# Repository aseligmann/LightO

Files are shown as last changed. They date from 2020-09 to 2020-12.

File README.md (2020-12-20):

# LightO

LightO is an open remote-controlled light project.

The project is based around an ESP32 driving a string of addressable LEDs, in this case a custom PCB with 61 SK6812 RGBW LEDs.

The user is able to control the LightO through an intuitive web-based interface, consisting of color-wheel and slider control.
The brightness of the light is user-controlled and can be driven at up to roughly 15 W, for an eye-scorching brightness level.

The LightO has 3 modes which can be selected from the interface:

* **Colour** - User defines a colour to display
* **Candle** - Simulates a flickering candle
* **Cycle** - Cycles through the colour-spectrum

The light is powered by a single USB-C port. 

### Images
Front

Front

Left side

Back

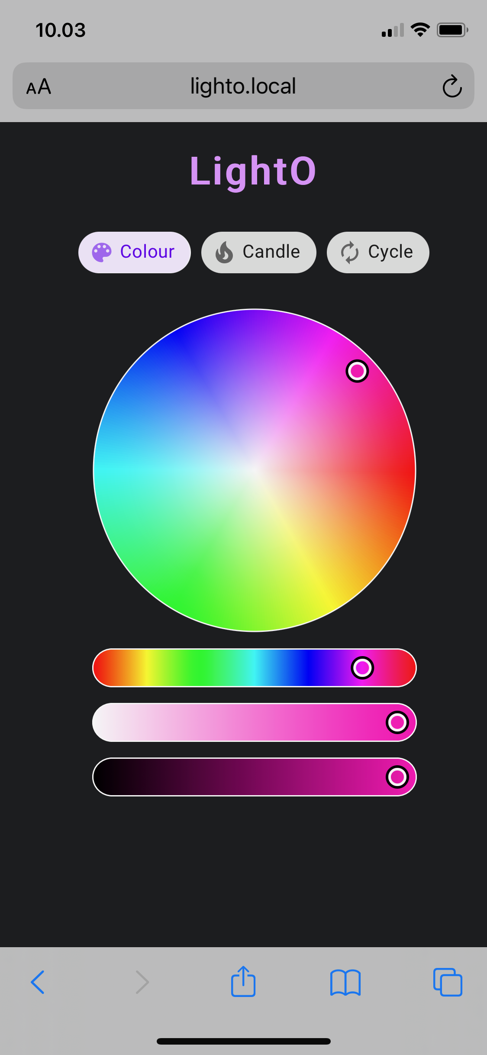
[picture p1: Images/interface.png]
Interface


### Features
- Full control of colour and brightness (RGBW channels) for all LEDs
- USB-C powered
- WiFi based control with user-centered design
- Intuitive captive AP for setup

### Development
- [ ] Provide schematic for ESP32 piggyback board
- [ ] Wake-up mode simulating a sunrise at a userdefined time
- [ ] Migrate code to PlatformIO
- [ ] Integrate USB-C PD and ESP32 on LED PCB

### Bill of Materials

#### PCB
* 1x 160 mm LightO PCB (light_160mm_v1_0_2020-04-21)
* 61x SK6812 LEDs
* 61x 5050 LED lenses, wide angle (optional)
* 61x 0805 100 nF capacitors
* 2x JST-XH 2-pin straight connectors

#### ESP32
* 1x ESP32 development board
* 1x 100 uF capacitor
* 2x 330 Ohm resistors

#### Power-delivery
* 1x USB-C PD module (ZY12PDN)

#### Misc.
* 7x M3 bolts (16 mm)
* 7x M3 nuts
* 3x 2.2x9.5 self-tapping screws

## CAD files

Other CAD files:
Hardware/Model/Parts/AcrylicFront/AcrylicFront_v1.0.DWG

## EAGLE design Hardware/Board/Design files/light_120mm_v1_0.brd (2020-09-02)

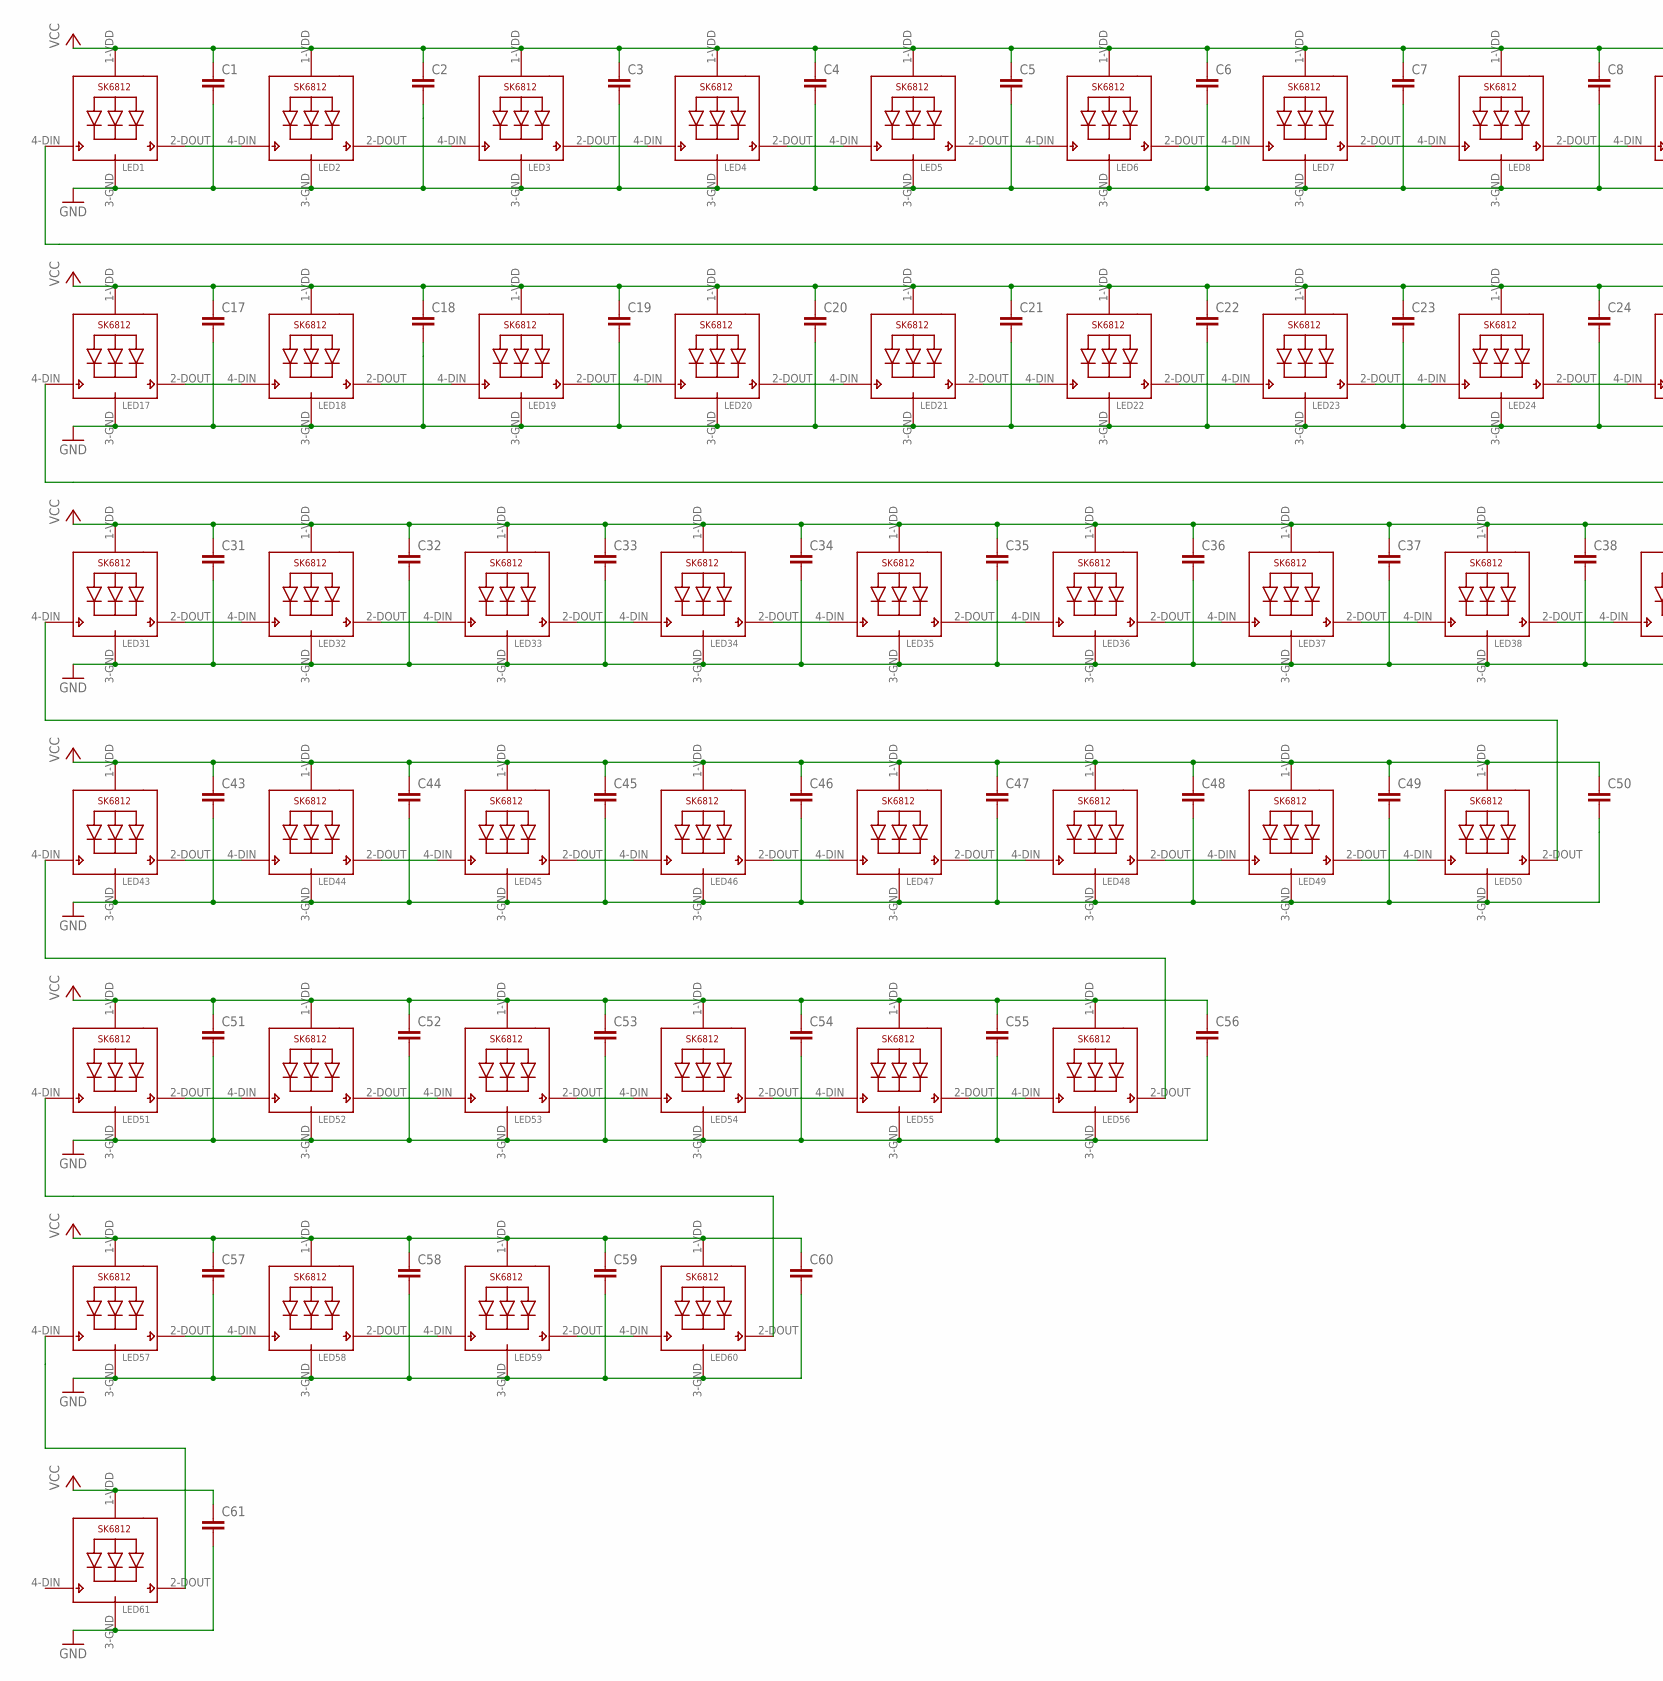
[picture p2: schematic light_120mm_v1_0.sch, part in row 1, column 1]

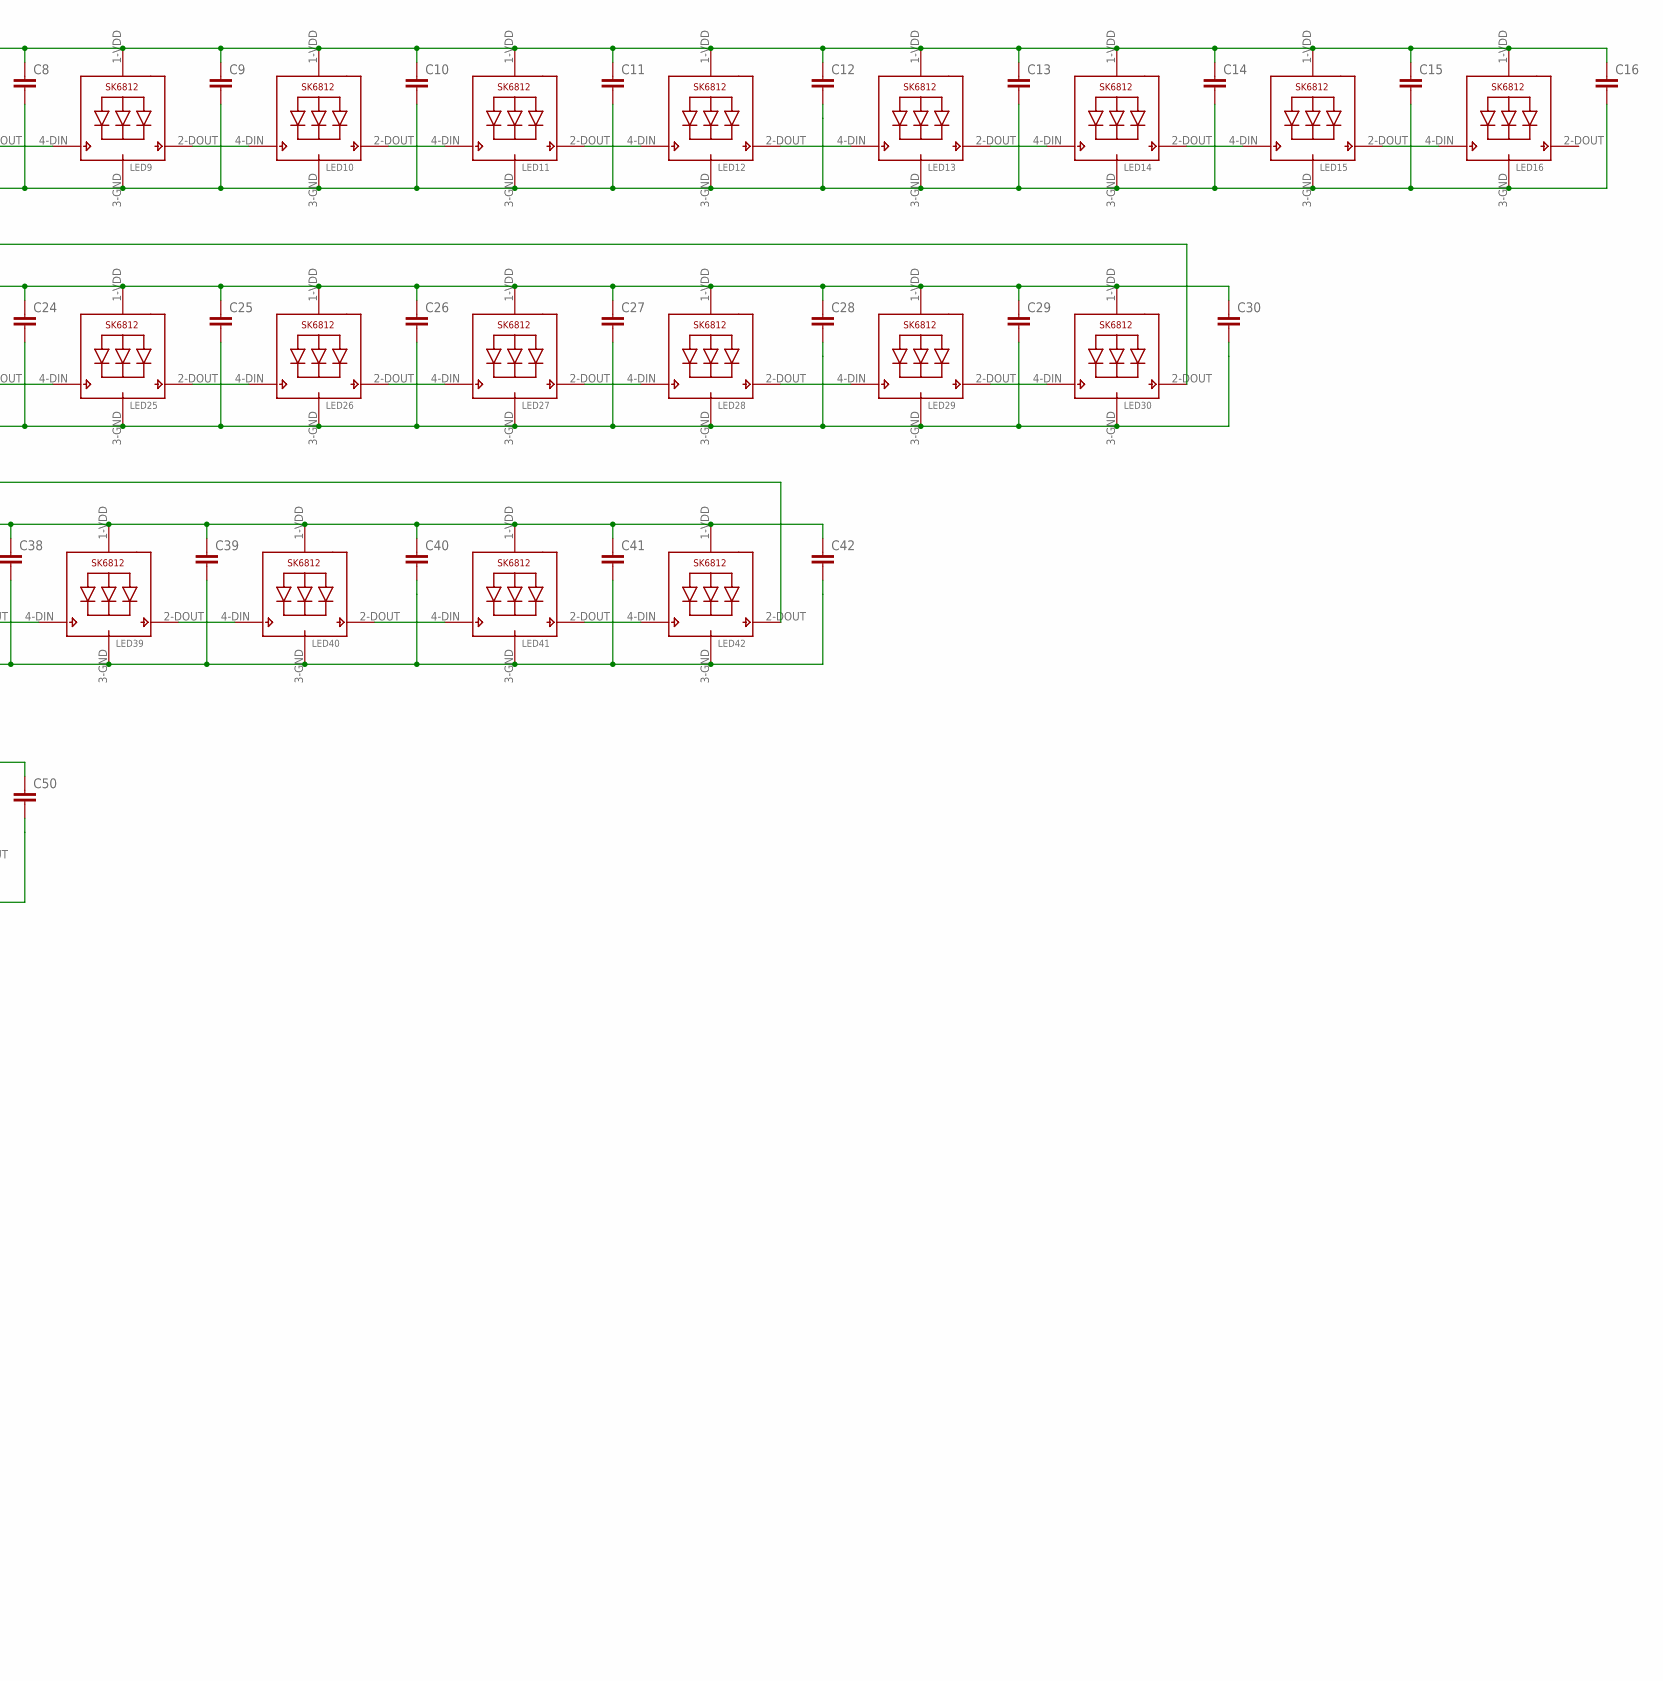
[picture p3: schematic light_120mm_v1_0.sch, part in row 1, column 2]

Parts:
C1, C2, C3, C4, C5, C6, C7, C8, C9, C10, C11, C12, C13, C14, C15, C16, C17, C18, C19, C20, C21, C22, C23, C24, C25, C26, C27, C28, C29, C30, C31, C32, C33, C34, C35, C36, C37, C38, C39, C40, C41, C42, C43, C44, C45, C46, C47, C48, C49, C50, C51, C52, C53, C54, C55, C56, C57, C58, C59, C60, C61: C-EUC0805; C0805
LED1, LED2, LED3, LED4, LED5, LED6, LED7, LED8, LED9, LED10, LED11, LED12, LED13, LED14, LED15, LED16, LED17, LED18, LED19, LED20, LED21, LED22, LED23, LED24, LED25, LED26, LED27, LED28, LED29, LED30, LED31, LED32, LED33, LED34, LED35, LED36, LED37, LED38, LED39, LED40, LED41, LED42, LED43, LED44, LED45, LED46, LED47, LED48, LED49, LED50, LED51, LED52, LED53, LED54, LED55, LED56, LED57, LED58, LED59, LED60, LED61: SK6812_5050W; LED5050_W

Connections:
GND: C1.2, C2.2, C3.2, C4.2, C5.2, C6.2, C7.2, C8.2, C9.2, C10.2, C11.2, C12.2, C13.2, C14.2, C15.2, C16.2, C17.2, C18.2, C19.2, C20.2, C21.2, C22.2, C23.2, C24.2, C25.2, C26.2, C27.2, C28.2, C29.2, C30.2, C31.2, C32.2, C33.2, C34.2, C35.2, C36.2, C37.2, C38.2, C39.2, C40.2, C41.2, C42.2, C43.2, C44.2, C45.2, C46.2, C47.2, C48.2, C49.2, C50.2, C51.2, C52.2, C53.2, C54.2, C55.2, C56.2, C57.2, C58.2, C59.2, C60.2, C61.2, LED1.3-GND (GND), LED2.3-GND (GND), LED3.3-GND (GND), LED4.3-GND (GND), LED5.3-GND (GND), LED6.3-GND (GND), LED7.3-GND (GND), LED8.3-GND (GND), LED9.3-GND (GND), LED10.3-GND (GND), LED11.3-GND (GND), LED12.3-GND (GND), LED13.3-GND (GND), LED14.3-GND (GND), LED15.3-GND (GND), LED16.3-GND (GND), LED17.3-GND (GND), LED18.3-GND (GND), LED19.3-GND (GND), LED20.3-GND (GND), LED21.3-GND (GND), LED22.3-GND (GND), LED23.3-GND (GND), LED24.3-GND (GND), LED25.3-GND (GND), LED26.3-GND (GND), LED27.3-GND (GND), LED28.3-GND (GND), LED29.3-GND (GND), LED30.3-GND (GND), LED31.3-GND (GND), LED32.3-GND (GND), LED33.3-GND (GND), LED34.3-GND (GND), LED35.3-GND (GND), LED36.3-GND (GND), LED37.3-GND (GND), LED38.3-GND (GND), LED39.3-GND (GND), LED40.3-GND (GND), LED41.3-GND (GND), LED42.3-GND (GND), LED43.3-GND (GND), LED44.3-GND (GND), LED45.3-GND (GND), LED46.3-GND (GND), LED47.3-GND (GND), LED48.3-GND (GND), LED49.3-GND (GND), LED50.3-GND (GND), LED51.3-GND (GND), LED52.3-GND (GND), LED53.3-GND (GND), LED54.3-GND (GND), LED55.3-GND (GND), LED56.3-GND (GND), LED57.3-GND (GND), LED58.3-GND (GND), LED59.3-GND (GND), LED60.3-GND (GND), LED61.3-GND (GND)
unnamed: LED1.2-DOUT (DO), LED2.4-DIN (DI)
unnamed: LED2.2-DOUT (DO), LED3.4-DIN (DI)
unnamed: LED3.2-DOUT (DO), LED4.4-DIN (DI)
unnamed: LED4.2-DOUT (DO), LED5.4-DIN (DI)
unnamed: LED5.2-DOUT (DO), LED6.4-DIN (DI)
unnamed: LED6.2-DOUT (DO), LED7.4-DIN (DI)
unnamed: LED7.2-DOUT (DO), LED8.4-DIN (DI)
unnamed: LED8.2-DOUT (DO), LED9.4-DIN (DI)
unnamed: LED9.2-DOUT (DO), LED10.4-DIN (DI)
unnamed: LED10.2-DOUT (DO), LED11.4-DIN (DI)
unnamed: LED11.2-DOUT (DO), LED12.4-DIN (DI)
unnamed: LED12.2-DOUT (DO), LED13.4-DIN (DI)
unnamed: LED13.2-DOUT (DO), LED14.4-DIN (DI)
unnamed: LED14.2-DOUT (DO), LED15.4-DIN (DI)
unnamed: LED15.2-DOUT (DO), LED16.4-DIN (DI)
unnamed: LED43.4-DIN (DI), LED56.2-DOUT (DO)
unnamed: LED17.2-DOUT (DO), LED18.4-DIN (DI)
unnamed: LED18.2-DOUT (DO), LED19.4-DIN (DI)
unnamed: LED19.2-DOUT (DO), LED20.4-DIN (DI)
unnamed: LED20.2-DOUT (DO), LED21.4-DIN (DI)
unnamed: LED21.2-DOUT (DO), LED22.4-DIN (DI)
unnamed: LED22.2-DOUT (DO), LED23.4-DIN (DI)
unnamed: LED23.2-DOUT (DO), LED24.4-DIN (DI)
unnamed: LED24.2-DOUT (DO), LED25.4-DIN (DI)
unnamed: LED25.2-DOUT (DO), LED26.4-DIN (DI)
unnamed: LED26.2-DOUT (DO), LED27.4-DIN (DI)
unnamed: LED27.2-DOUT (DO), LED28.4-DIN (DI)
unnamed: LED28.2-DOUT (DO), LED29.4-DIN (DI)
unnamed: LED29.2-DOUT (DO), LED30.4-DIN (DI)
unnamed: LED31.4-DIN (DI), LED50.2-DOUT (DO)
unnamed: LED31.2-DOUT (DO), LED32.4-DIN (DI)
unnamed: LED32.2-DOUT (DO), LED33.4-DIN (DI)
unnamed: LED33.2-DOUT (DO), LED34.4-DIN (DI)
unnamed: LED34.2-DOUT (DO), LED35.4-DIN (DI)
unnamed: LED35.2-DOUT (DO), LED36.4-DIN (DI)
unnamed: LED36.2-DOUT (DO), LED37.4-DIN (DI)
unnamed: LED37.2-DOUT (DO), LED38.4-DIN (DI)
unnamed: LED38.2-DOUT (DO), LED39.4-DIN (DI)
unnamed: LED39.2-DOUT (DO), LED40.4-DIN (DI)
unnamed: LED40.2-DOUT (DO), LED41.4-DIN (DI)
unnamed: LED41.2-DOUT (DO), LED42.4-DIN (DI)
unnamed: LED17.4-DIN (DI), LED42.2-DOUT (DO)
unnamed: LED43.2-DOUT (DO), LED44.4-DIN (DI)
unnamed: LED44.2-DOUT (DO), LED45.4-DIN (DI)
unnamed: LED45.2-DOUT (DO), LED46.4-DIN (DI)
unnamed: LED46.2-DOUT (DO), LED47.4-DIN (DI)
unnamed: LED47.2-DOUT (DO), LED48.4-DIN (DI)
unnamed: LED48.2-DOUT (DO), LED49.4-DIN (DI)
unnamed: LED49.2-DOUT (DO), LED50.4-DIN (DI)
unnamed: LED1.4-DIN (DI), LED30.2-DOUT (DO)
unnamed: LED51.2-DOUT (DO), LED52.4-DIN (DI)
unnamed: LED52.2-DOUT (DO), LED53.4-DIN (DI)
unnamed: LED53.2-DOUT (DO), LED54.4-DIN (DI)
unnamed: LED54.2-DOUT (DO), LED55.4-DIN (DI)
unnamed: LED55.2-DOUT (DO), LED56.4-DIN (DI)
unnamed: LED57.4-DIN (DI), LED61.2-DOUT (DO)
unnamed: LED57.2-DOUT (DO), LED58.4-DIN (DI)
unnamed: LED58.2-DOUT (DO), LED59.4-DIN (DI)
unnamed: LED59.2-DOUT (DO), LED60.4-DIN (DI)
unnamed: LED51.4-DIN (DI), LED60.2-DOUT (DO)
VCC: C1.1, C2.1, C3.1, C4.1, C5.1, C6.1, C7.1, C8.1, C9.1, C10.1, C11.1, C12.1, C13.1, C14.1, C15.1, C16.1, C17.1, C18.1, C19.1, C20.1, C21.1, C22.1, C23.1, C24.1, C25.1, C26.1, C27.1, C28.1, C29.1, C30.1, C31.1, C32.1, C33.1, C34.1, C35.1, C36.1, C37.1, C38.1, C39.1, C40.1, C41.1, C42.1, C43.1, C44.1, C45.1, C46.1, C47.1, C48.1, C49.1, C50.1, C51.1, C52.1, C53.1, C54.1, C55.1, C56.1, C57.1, C58.1, C59.1, C60.1, C61.1, LED1.1-VDD (VDD), LED2.1-VDD (VDD), LED3.1-VDD (VDD), LED4.1-VDD (VDD), LED5.1-VDD (VDD), LED6.1-VDD (VDD), LED7.1-VDD (VDD), LED8.1-VDD (VDD), LED9.1-VDD (VDD), LED10.1-VDD (VDD), LED11.1-VDD (VDD), LED12.1-VDD (VDD), LED13.1-VDD (VDD), LED14.1-VDD (VDD), LED15.1-VDD (VDD), LED16.1-VDD (VDD), LED17.1-VDD (VDD), LED18.1-VDD (VDD), LED19.1-VDD (VDD), LED20.1-VDD (VDD), LED21.1-VDD (VDD), LED22.1-VDD (VDD), LED23.1-VDD (VDD), LED24.1-VDD (VDD), LED25.1-VDD (VDD), LED26.1-VDD (VDD), LED27.1-VDD (VDD), LED28.1-VDD (VDD), LED29.1-VDD (VDD), LED30.1-VDD (VDD), LED31.1-VDD (VDD), LED32.1-VDD (VDD), LED33.1-VDD (VDD), LED34.1-VDD (VDD), LED35.1-VDD (VDD), LED36.1-VDD (VDD), LED37.1-VDD (VDD), LED38.1-VDD (VDD), LED39.1-VDD (VDD), LED40.1-VDD (VDD), LED41.1-VDD (VDD), LED42.1-VDD (VDD), LED43.1-VDD (VDD), LED44.1-VDD (VDD), LED45.1-VDD (VDD), LED46.1-VDD (VDD), LED47.1-VDD (VDD), LED48.1-VDD (VDD), LED49.1-VDD (VDD), LED50.1-VDD (VDD), LED51.1-VDD (VDD), LED52.1-VDD (VDD), LED53.1-VDD (VDD), LED54.1-VDD (VDD), LED55.1-VDD (VDD), LED56.1-VDD (VDD), LED57.1-VDD (VDD), LED58.1-VDD (VDD), LED59.1-VDD (VDD), LED60.1-VDD (VDD), LED61.1-VDD (VDD)

Board: 2 copper layers, 122 parts (0 on the bottom side), 62 nets, no tracks yet.

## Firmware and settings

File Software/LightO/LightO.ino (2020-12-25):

// Import required libraries
#include "WiFi.h"
#include <ESPmDNS.h> // For user-friendly web address
#include <WiFiClient.h>
//// https://github.com/me-no-dev/ESPAsyncWebServer/issues/418#issuecomment-667976368
#include <WiFiManager.h> // Captive AP to configure new network
WiFiManager wifiManager;
#define WEBSERVER_H
#include "ESPAsyncWebServer.h" // Web server
////
#include "SPIFFS.h" // Data storage
#include "math.h"
#include <NeoPixelBus.h> // LED control


// Debugging //////////////////////////////////////////////////////////////////////////
bool debug = false;


// Multi-core definitions //////////////////////////////////////////////////////////////////////////
TaskHandle_t taskCore0;
TaskHandle_t taskCore1;
SemaphoreHandle_t taskSemaphore;



// LED Definitions //////////////////////////////////////////////////////////////////////////
#define NUM_LEDS 61
#define DATA_PIN 32

#define brightnessDefault 255

// four element pixels, RGBW
NeoPixelBus<NeoGrbwFeature, Neo800KbpsMethod> strip(NUM_LEDS, DATA_PIN);

RgbwColor red = RgbwColor(brightnessDefault, 0, 0, 0);
RgbwColor green = RgbwColor(0, brightnessDefault, 0, 0);
RgbwColor blue = RgbwColor(0, 0, brightnessDefault, 0);
RgbwColor white = RgbwColor(0, 0, 0, brightnessDefault);
RgbwColor black = RgbwColor(0, 0, 0, 0);

//HslColor hslRed(red);
//HslColor hslGreen(green);
//HslColor hslBlue(blue);
//HslColor hslWhite(white);
//HslColor hslBlack(black);

// Set status LED GPIO
const int switchPin = 23;

// Stores LED state
String ledState;

// LED colors
int hue = 0;
int sat = 100;
int val = 100;
int r;
int g;
int b;
int w;
bool colorUpdate;

//// Modes
// Colorwheel
// Candle
int timeCandleWaitR = 0;
int timeCandleWaitG = 0;
int timeCandleR = 0;
int timeCandleG = 0;
// Cycle
int timeCycleStep = 50;
float hueFloat = 0;

// Timing
long t;
long t_prev;


// Server Definitions //////////////////////////////////////////////////////////////////////////
// Variable to hold HTTP request
const char* PARAM_INPUT_1 = "h";
const char* PARAM_INPUT_2 = "s";
const char* PARAM_INPUT_3 = "v";
const char* PARAM_MODE = "mode";

int lampMode = 0;
// 0 = setup
// 1 = colorwheel
// 2 = candle
// 3 = cycle
 
// Create AsyncWebServer object on port 80
AsyncWebServer server(80);

// Toggle GPIO
String handleSwitch(const String& var) {
  Serial.println(var);
  if (var == "STATE") {
    if (digitalRead(switchPin)) {
      ledState = "ON";
    } else {
      ledState = "OFF";
    }
    Serial.print(ledState);
    return ledState;
  }
  return String();
}

int lastColorUpdate = 0;
int intervalColorUpdate = 100; // ms


// LED functions ////////////////////////////////////////////////////////////////////////////////
// Convert from HSV to RGB
void HSV_to_RGB(int hueIn, int satIn, int valIn) {
  int i;
  double f, p, q, t, h, s, v;

  h = max(0.0, min(360.0, (double) hueIn));
  s = max(0.0, min(100.0, (double) satIn));
  v = max(0.0, min(100.0, (double) valIn));

  s /= 100.0;
  v /= 100.0;

  if (s == 0) {
    // Achromatic (grey)
    r = 0;
    g = 0;
    b = 0;
    return;
  }

  h /= 60.0; // sector 0 to 5
  i = (int) floor(h);
  f = h - i; // factorial part of h
  p = v * (1 - s);
  q = v * (1 - s * f);
  t = v * (1 - s * (1 - f));

  if (debug) {
    Serial.println("-------------- HSV_to_RGB --------------");
    Serial.print("h = ");
    Serial.print(h);
    Serial.print(", i = ");
    Serial.print(i);
    Serial.print(", f = ");
    Serial.println(f);
    Serial.print("v = ");
    Serial.print(v);
    Serial.print(", p = ");
    Serial.print(p);
    Serial.print(", q = ");
    Serial.print(q);
    Serial.print(", t = ");
    Serial.print(t);
    Serial.println();
  }
  
  switch (i) {
    case 1:
      r = (int) round(255 * q);
      g = (int) round(255 * v);
      b = (int) round(255 * p);
      break;
    case 2:
      r = (int) round(255 * p);
      g = (int) round(255 * v);
      b = (int) round(255 * t);
      break;
    case 3:
      r = (int) round(255 * p);
      g = (int) round(255 * q);
      b = (int) round(255 * v);
      break;
    case 4:
      r = (int) round(255 * t);
      g = (int) round(255 * p);
      b = (int) round(255 * v);
      break;
    case 5:
      r = (int) round(255 * v);
      g = (int) round(255 * p);
      b = (int) round(255 * q);
      break;
    default: // case 0
      r = (int) round(255 * v);
      g = (int) round(255 * t);
      b = (int) round(255 * p);
      break;
  }
  
  if (debug) {
    Serial.println("-------------- HSV_to_RGB --------------");
    Serial.print("R = ");
    Serial.print(r);
    Serial.print(", G = ");
    Serial.print(g);
    Serial.print(", B = ");
    Serial.print(b);
    Serial.println();
  }
}


// Handle input color
void handleColor(int hueIn, int satIn, int valIn) {
  // We interpret hue as color, saturation as luminance and value as brightness.
  // This is a bit unconventional, but makes for a better user experience
  
  if (debug) {
    Serial.println("============== handleColor INPUT ==============");
    Serial.print("Hue = ");
    Serial.print(hueIn);
    Serial.print(", Sat = ");
    Serial.print(satIn);
    Serial.print(", Val = ");
    Serial.print(valIn);
    Serial.println();
  }
  
  HSV_to_RGB(hueIn, satIn, valIn);
  //RGB_to_RGBW(r, g, b);
  
  float lum = satIn / 100.0;
  float bright = valIn / 100.0;
  
  r = (int) (bright * lum * r);
  g = (int) (bright * lum * g);
  b = (int) (bright * lum * b);
  w = (int) 255 * (bright * (1.0 - lum));

  if (debug) {
    Serial.println("-------------- handleColor OUTPUT --------------");
    Serial.print("R = ");
    Serial.print(r);
    Serial.print(", G = ");
    Serial.print(g);
    Serial.print(", B = ");
    Serial.print(b);
    Serial.print(", W = ");
    Serial.print(w);
    Serial.println();
    Serial.println("===============================================");
    Serial.println();
  }
}


// Convenience function for setting hue, sat and val, and setting the colorUpdate flag
void colorSet(int hueIn, int satIn, int valIn){
  hue = hueIn;
  sat = satIn;
  val = valIn;
  colorUpdate = true;
}


// Set color of select pixels
void colorSelect(RgbwColor color, int pxStart, int pxEnd) {
  for (uint16_t i = pxStart; i < pxEnd; i++) {
    strip.SetPixelColor(i, color);
  }
  strip.Show();
}


// Set color of all pixels
void colorAll(RgbwColor color) {
  colorSelect(color, 0, strip.PixelCount());
}


// Fade from one color to another
void fade(RgbwColor colorStart, RgbwColor colorEnd, float progressInc, int waitMillis) {
  Serial.println("fade()");
  float progress = 0.0;
  while (progress <= 1.0) {
    Serial.print("\tProgress: ");
    Serial.println(progress);
    RgbwColor updatedColor = RgbwColor::LinearBlend(colorStart, colorEnd, progress);
    colorAll(updatedColor);
    delay(waitMillis);
    progress = progress + progressInc;
  }
}


// Cycle through brightness-levels and colors
void cycleColor(int brightness, int waitMillis) {
  Serial.println("cycleColor()");
  if (brightness > 255) {
    brightness = 255;
  }
  if (brightness < 0) {
    brightness = 0;
  }

  Serial.println("\tRED");
  colorAll(RgbwColor(brightness, 0, 0, 0)); // Full RED
  delay(waitMillis);

  Serial.println("\tGREEN");
  colorAll(RgbwColor(0, brightness, 0, 0)); // Full GREEN
  delay(waitMillis);

  Serial.println("\tBLUE");
  colorAll(RgbwColor(0, 0, brightness, 0)); // Full BLUE
  delay(waitMillis);

  Serial.println("\tWHITE");
  colorAll(RgbwColor(0, 0, 0, brightness)); // Full WHITE
  delay(waitMillis);
}


// Cycle through brightness-levels and colors
void cycleAll(int brightnessStart, int brightnessEnd, int steps, int waitFade, int waitColor) {
  Serial.println("cycleAll()");
  float progressInc = 1 / ((float) steps);

  Serial.println("\tRED");
  RgbwColor colorStart = RgbwColor(brightnessStart, 0, 0, 0); // RED
  RgbwColor colorEnd = RgbwColor(brightnessEnd, 0, 0, 0);
  fade(colorStart, colorEnd, progressInc, waitFade);
  delay(waitColor);

  Serial.println("\tBLUE");
  colorStart = RgbwColor(0, brightnessStart, 0, 0); // BLUE
  colorEnd = RgbwColor(0, brightnessEnd, 0, 0);
  fade(colorStart, colorEnd, progressInc, waitFade);
  delay(waitColor);

  Serial.println("\tGREEN");
  colorStart = RgbwColor(0, 0, brightnessStart, 0); // GREEN
  colorEnd = RgbwColor(0, 0, brightnessEnd, 0);
  fade(colorStart, colorEnd, progressInc, waitFade);
  delay(waitColor);

  Serial.println("\tWHITE");
  colorStart = RgbwColor(0, 0, 0, brightnessStart); // WHITE
  colorEnd = RgbwColor(0, 0, 0, brightnessEnd);
  fade(colorStart, colorEnd, progressInc, waitFade);
}


// Set pixels one at a time
void colorWipe(RgbwColor color, int wait) {
  Serial.println("colorWipe()");
  for (int i = 0; i < strip.PixelCount(); i++) { // For each pixel in strip...
    Serial.print("\tLED: ");
    Serial.println(i + 1);
    strip.SetPixelColor(i, color);         //  Set pixel's color (in RAM)
    strip.Show();                          //  Update strip to match
    delay(wait);                           //  Pause for a moment
  }
}


// Go through all 4 colors by setting pixels one at a time
void colorWipeAll(int brightness, int wait) {
  Serial.println("colorWipeAll()");

  Serial.print("\tRED");
  colorWipe(RgbwColor(brightness, 0, 0, 0), wait);

  Serial.print("\tBLUE");
  colorWipe(RgbwColor(0, brightness, 0, 0), wait);

  Serial.print("\tGREEN");
  colorWipe(RgbwColor(0, 0, brightness, 0), wait);

  Serial.print("\tWHITE");
  colorWipe(RgbwColor(0, 0, 0, brightness), wait);
}
















void setup() {
  // Serial port for debugging purposes
  Serial.begin(115200);

  Serial.println();
  Serial.println("Initializing...");
  Serial.flush();

  // Set LED output
  pinMode(switchPin, OUTPUT);

  lampMode = 0;



  // LED stuff ////////////////////////////////////////////////////////////////////////////////
  Serial.println("Setting up LEDs...");
  // Reset all the pixels to the off state
  strip.Begin();
  strip.Show();
  RgbwColor colorWiFi = RgbwColor(0, 0, 255, 0);
  RgbwColor colorServer = RgbwColor(0, 255, 255, 0);
  RgbwColor colorDone = RgbwColor(0, 255, 0, 0);
  RgbwColor colorFailure = RgbwColor(255, 0, 0, 0);
  RgbwColor colorOff = RgbwColor(0, 0, 0, 0);



  // SPIFFS ////////////////////////////////////////////////////////////////////////////////
  // Initialize SPIFFS file server
  if (!SPIFFS.begin(true)) {
    Serial.println("An Error has occurred while mounting SPIFFS");
    return;
  }



  // Wi-Fi ////////////////////////////////////////////////////////////////////////////////
  // Wi-Fi feedback
  Serial.println("Set leds blue for Wi-Fi stage...");
  colorSelect(colorWiFi, 45, strip.PixelCount()); // Outermost ring
  colorSelect(colorOff, 31, 45); // Next-outermost ring
  int timeWiFi = millis(); // Track time
  
  // Connect to Wi-Fi
  //WiFi.begin(ssid, password);
  //while (WiFi.status() != WL_CONNECTED) {
  //  delay(1000);
  //  Serial.println("Connecting to WiFi..");
  //}

  // Print IP address of web server on serial interface
  //Serial.println(WiFi.localIP());
  
  // WiFiManager
  // reset settings - for testing
  //wifiManager.resetSettings();

  // Sets timeout until configuration portal gets turned off
  // Useful to make it all retry or go to sleep
  // In seconds
  wifiManager.setTimeout(180);
  wifiManager.setClass("invert"); // Dark theme
  
  // Fetches ssid and pass and tries to connect
  // If it does not connect it starts an access point with the specified name "LightO"
  // Goes into a blocking loop awaiting configuration
  if(!wifiManager.autoConnect("LightO")) {
    colorSelect(colorFailure, 31, 45); // Next-outermost ring
    Serial.println("Failed to connect and hit timeout");
    delay(3000);
    // Reset and try again
    ESP.restart();
    delay(5000);
  } 

  Serial.println("WiFi configured and connected");
  while(millis() - timeWiFi < 200) {
    // Wait for 200 ms to have passed since showing WiFi feedback
    // Purely to avoid flashing LEDs too quickly as the user won't notice
  }



  // Server ////////////////////////////////////////////////////////////////////////////////
  // Server feedback
  Serial.println("Set leds teal for Server stage...");
  colorSelect(colorServer, 45, strip.PixelCount()); // Outermost ring
  colorSelect(colorOff, 31, 45); // Next-outermost ring
  int timeServer = millis(); // Track time
  
  // Route for root / web page
  server.on("/", HTTP_GET, [](AsyncWebServerRequest * request) {
    request->send(SPIFFS, "/index.html", String(), false, handleSwitch);
  });

  // Route to load style.css file
  server.on("/style.css", HTTP_GET, [](AsyncWebServerRequest * request) {
    request->send(SPIFFS, "/style.css", "text/css");
  });

  // Route to set GPIO to HIGH
  server.on("/on", HTTP_GET, [](AsyncWebServerRequest * request) {
    digitalWrite(switchPin, HIGH);
    Serial.println("Switch: ON");
    request->send(SPIFFS, "/index.html", String(), false, handleSwitch);
  });

  // Route to set GPIO to LOW
  server.on("/off", HTTP_GET, [](AsyncWebServerRequest * request) {
    digitalWrite(switchPin, LOW);
    Serial.println("Switch: OFF");
    request->send(SPIFFS, "/index.html", String(), false, handleSwitch);
  });

  // Change mode
  server.on("/mode", HTTP_GET, [](AsyncWebServerRequest * request) {
    
    String getMode;
    
    // GET input1 value on <ESP_IP>/get?h=<inputMessage>
    if (request->hasParam(PARAM_MODE)) {
      getMode = request->getParam(PARAM_MODE)->value();
      lampMode = (int) getMode.toInt();
      hueFloat = hue;
    }

    if (debug) {
      Serial.println("=============== WebServer /mode ===============");
      Serial.print("Time = ");
      Serial.println(millis());
      Serial.println("Got new mode:");
      Serial.print("Mode = ");
      Serial.print(lampMode);
      Serial.println();
      Serial.println("===============================================");
      Serial.println();
    }
    
    request->send(200);
  });

  server.on("/favicon.ico", HTTP_GET, [](AsyncWebServerRequest * request) {
    request->send(SPIFFS, "/favicon.ico", "image/png");
  });

  server.on("/stateHSV", HTTP_GET, [](AsyncWebServerRequest *request){
    char state[12];
    sprintf(state, "%d,%d,%d", hue, sat, val);

    if (debug) {
      Serial.println("=============== WebServer /stateHSV ===============");
      Serial.print("Time = ");
      Serial.println(millis());
      Serial.println("Got request for COLOR state. Sending:");
      Serial.print("Hue = ");
      Serial.print(hue);
      Serial.print(", Sat = ");
      Serial.print(sat);
      Serial.print(", Val = ");
      Serial.print(val);
      Serial.println();
      Serial.println("===============================================");
      Serial.println();
    }
    
    request->send(200, "text/plain", state);
  });

  server.on("/stateMode", HTTP_GET, [](AsyncWebServerRequest *request){
    char state[12];
    sprintf(state, "%d", lampMode);

    if (debug) {
      Serial.println("=============== WebServer /stateMode ===============");
      Serial.print("Time = ");
      Serial.println(millis());
      Serial.println("Got request for MODE state. Sending:");
      Serial.print("Mode = ");
      Serial.print(lampMode);
      Serial.println();
      Serial.println("===============================================");
      Serial.println();
    }
    
    request->send(200, "text/plain", state);
  });

  server.on("/get", HTTP_GET, [](AsyncWebServerRequest * request) {
    // Handle semaphore
    xSemaphoreTake(taskSemaphore, portMAX_DELAY);

    String getHue;
    String getSat;
    String getVal;
    
    // GET input1 value on <ESP_IP>/get?h=<inputMessage>
    if (request->hasParam(PARAM_INPUT_1)) {
      getHue = request->getParam(PARAM_INPUT_1)->value();
      hue = (int) getHue.toInt();
    }

    // GET input2 value on <ESP_IP>/get?s=<inputMessage>
    if (request->hasParam(PARAM_INPUT_2)) {
      getSat = request->getParam(PARAM_INPUT_2)->value();
      sat = (int) getSat.toInt();
    }

    // GET input3 value on <ESP_IP>/get?v=<inputMessage>
    if (request->hasParam(PARAM_INPUT_3)) {
      getVal = request->getParam(PARAM_INPUT_3)->value();
      val = (int) getVal.toInt();
    }
    
    // Set flag
    colorUpdate = true;
    
    if (debug) {
      Serial.println("=============== WebServer /get ===============");
      Serial.print("Time = ");
      Serial.println(millis());
      Serial.println("Got new color:");
      Serial.print("Hue = ");
      Serial.print(hue);
      Serial.print(", Sat = ");
      Serial.print(sat);
      Serial.print(", Val = ");
      Serial.print(val);
      Serial.println();
      Serial.println("===============================================");
      Serial.println();
    }
    
    request->send(200);

    // Make semaphore available
    xSemaphoreGive(taskSemaphore);
  });

  // Start server
  server.begin();

  // Set up mDNS responder:
  // - first argument is the domain name, in this example
  //   the fully-qualified domain name is "LightO.local"
  // - second argument is the IP address to advertise
  //   we send our IP address on the WiFi network
  if (!MDNS.begin("LightO")) {
    Serial.println("Error setting up MDNS responder!");
    while (1) {
      colorSelect(colorFailure, 31, 45); // Next-outermost ring
      delay(1000);
    }
  }
  Serial.println("mDNS responder started");

  // Start TCP (HTTP) server
  server.begin();
  Serial.println("TCP server started");

  // Add service to MDNS-SD
  MDNS.addService("http", "tcp", 80);
  
  Serial.println("WiFi configured and launched");
  while(millis() - timeServer < 200) {
    // Wait for 200 ms to have passed since showing WiFi feedback
    // Purely to avoid flashing LEDs too quickly as the user won't notice
  }



  // Multi-core stuff ////////////////////////////////////////////////////////////////////////////////
  Serial.println("Finalising and starting multi-core execution...");
  
  taskSemaphore = xSemaphoreCreateMutex();
  
  // Create a task that will be executed in the taskCore0Handler() function, with priority 1 and executed on core 0
  xTaskCreatePinnedToCore(
    &taskCore0Handler,  /* Task function. */
    "task0",            /* name of task. */
    10000,              /* Stack size of task */
    NULL,               /* parameter of the task */
    1,                  /* priority of the task */
    &taskCore0,         /* Task handle to keep track of created task */
    0);                 /* pin task to core 0 */
  delay(500);
  // Create a task that will be executed in the taskCore1Handler() function, with priority 1 and executed on core 0
  xTaskCreatePinnedToCore(
    &taskCore1Handler,  /* Task function. */
    "task1",            /* name of task. */
    10000,              /* Stack size of task */
    NULL,               /* parameter of the task */
    1,                  /* priority of the task */
    &taskCore1,         /* Task handle to keep track of created task */
    1);                 /* pin task to core 0 */



  // Boot feedback ////////////////////////////////////////////////////////////////////////////////
  Serial.println("Flashing leds green to indicate boot succesful...");
  colorSelect(colorDone, 45, strip.PixelCount()); // Outermost ring
  colorSelect(colorOff, 31, 45); // Next-outermost ring
  delay(200);
  colorSelect(colorOff, 45, strip.PixelCount()); // Outermost ring
  delay(200);
  
  lampMode = 1;
  colorSet(0, 0, 100); // White

  Serial.println("Done booting.");
  
}

void taskCore0Handler(void *pvParameters) {
  Serial.print("LED handler running on core ");
  Serial.println(xPortGetCoreID());

  while (true) {
    // Handle semaphore and update LEDS
    xSemaphoreTake(taskSemaphore, portMAX_DELAY);
    LEDHandler();
    xSemaphoreGive(taskSemaphore);

    // Delay for watchdog
    vTaskDelay(10);
  }
}


void taskCore1Handler(void *pvParameters) {
  Serial.print("Webpage running on core ");
  Serial.println(xPortGetCoreID());

  while (true) {
    //xSemaphoreTake(taskSemaphore, portMAX_DELAY);
    //WebHandler();
    //xSemaphoreGive(taskSemaphore);

    // Delay for watchdog
    vTaskDelay(10);
  }
}

void LEDHandler() {
  switch (lampMode) {
    case 0:
      handleModeSetup();
      break;
    case 1:
      handleModeColorWheel();
      break;
    case 2:
      handleModeCandle();
      break;
    case 3:
      handleModeCycle();
      break;
  }
}

void handleModeSetup() {
  if (colorUpdate) {
    int timeNow = millis();
    if (timeNow - lastColorUpdate > intervalColorUpdate) {
      // Convert colorspace
      handleColor(hue, sat, val);
      
      if (debug) {
        Serial.println("================= Setup =================");
        Serial.print("Updating color to R = ");
        Serial.print(r);
        Serial.print(", G = ");
        Serial.print(g);
        Serial.print(", B = ");
        Serial.print(b);
        Serial.print(", W = ");
        Serial.print(w);
        Serial.println();
        Serial.println("===============================================");
        Serial.println();
      }
    
      // Set color
      RgbwColor color = RgbwColor(r, g, b, w);
      colorSelect(color, 45, strip.PixelCount());
    
      // Reset flag
      colorUpdate = false;
      
      // Reset time
      lastColorUpdate = timeNow;
    }
  }
}
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
void loop()
{
  // Empty
  delay(1000);
}

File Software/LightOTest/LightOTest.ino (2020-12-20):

// Import required libraries
#include "math.h"
#include <NeoPixelBus.h> // LED control

// LED Definitions //////////////////////////////////////////////////////////////////////////
#define NUM_LEDS 61
#define DATA_PIN 32

#define brightnessDefault 255

// four element pixels, RGBW
NeoPixelBus<NeoGrbwFeature, Neo800KbpsMethod> strip(NUM_LEDS, DATA_PIN);


// Set color of all pixels
void colorAll(RgbwColor color) {
  for (uint16_t i = 0; i < strip.PixelCount(); i++) {
    strip.SetPixelColor(i, color);
  }
  strip.Show();
}


void setup() {
  // Serial port for debugging purposes
  Serial.begin(115200);

  Serial.println();
  Serial.println("Initializing...");
  Serial.flush();

  // Set LED output
  pinMode(DATA_PIN, OUTPUT);

  // LED stuff ////////////////////////////////////////////////////////////////////////////////
  Serial.println("Setting up LEDs...");
  // Reset all the pixels to the off state
  strip.Begin();
  strip.Show();
}


void loop() {
  delay(1000);
  RgbwColor colorR = RgbwColor(brightnessDefault, 0, 0, 0);
  colorAll(colorR);
  delay(1000);
  RgbwColor colorG = RgbwColor(0, brightnessDefault, 0, 0);
  colorAll(colorG);
  delay(1000);
  RgbwColor colorB = RgbwColor(0, 0, brightnessDefault, 0);
  colorAll(colorB);
  delay(1000);
  RgbwColor colorW = RgbwColor(0, 0, 0, brightnessDefault);
  colorAll(colorW);
  delay(1000);
  RgbwColor color0 = RgbwColor(0, 0, 0, 0);
  colorAll(color0);
}

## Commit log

2020-09-02 Add webpage get state of LEDs on load
2020-12-20 Complete overhaul. Add additional features, add test program, add additional parts, add images, update readme
    [AcrylicFront_v1.0.DWG, light_120mm_v1_0.brd, light_120mm_v1_0.sch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]
2025-08-05 Add WLED ledmap for matrix support
    https://kno.wled.ge/advanced/mapping/
